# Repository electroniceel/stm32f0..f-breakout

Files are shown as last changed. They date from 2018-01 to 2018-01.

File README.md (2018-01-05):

STM32F0..F (TSSOP20) Breakout Module
====================================

A breakout module for STM32F0 microcontrollers in TSSOP20 footprint.

Basic Features
--------------

* Focus on small footprint and direct access to all pins.
* Provides a 8 pin Micro-MaTch header for easy access to SWD and UART.
* Pushbutton for Reset (press <1 second) and starting the bootloader (press >3 seconds).
* Onboard LDO regulator (standard SOT-23-5) can be used for VDD and VDDA, just VDD or disabled completely.
* Use of a crystal (SMT 3.2x2.5mm) is optional.
* Options can be configured using solder bridges.
* Power LED and User LED (on PA0, PF1 or disconnected).
* Size: 20x32mm or 10x8 pins in the standard 2.54mm raster

Currently supported microcontrollers
------------------------------------

* STM32F030F4
* STM32F031F4
* STM32F031F6
* STM32F038F6
* STM32F042F4 (USB header must be connected externally)
* STM32F042F6 (USB header must be connected externally)
* STM32F070F6 (USB header must be connected externally)

Schematics & Layout
-------------------

Schematics & Layout were done in KiCAD.

[Schematics as PDF](https://github.com/electroniceel/stm32f0..f-breakout/raw/master/schematics.pdf)

Picture
-------

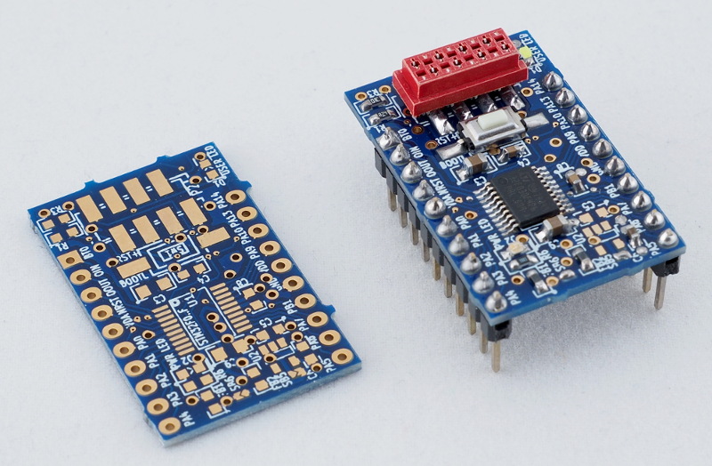
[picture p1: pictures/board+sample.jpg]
Module and raw PCB


License
-------


This work is licensed under a [Creative Commons Attribution 4.0 International License](https://creativecommons.org/licenses/by/4.0/).

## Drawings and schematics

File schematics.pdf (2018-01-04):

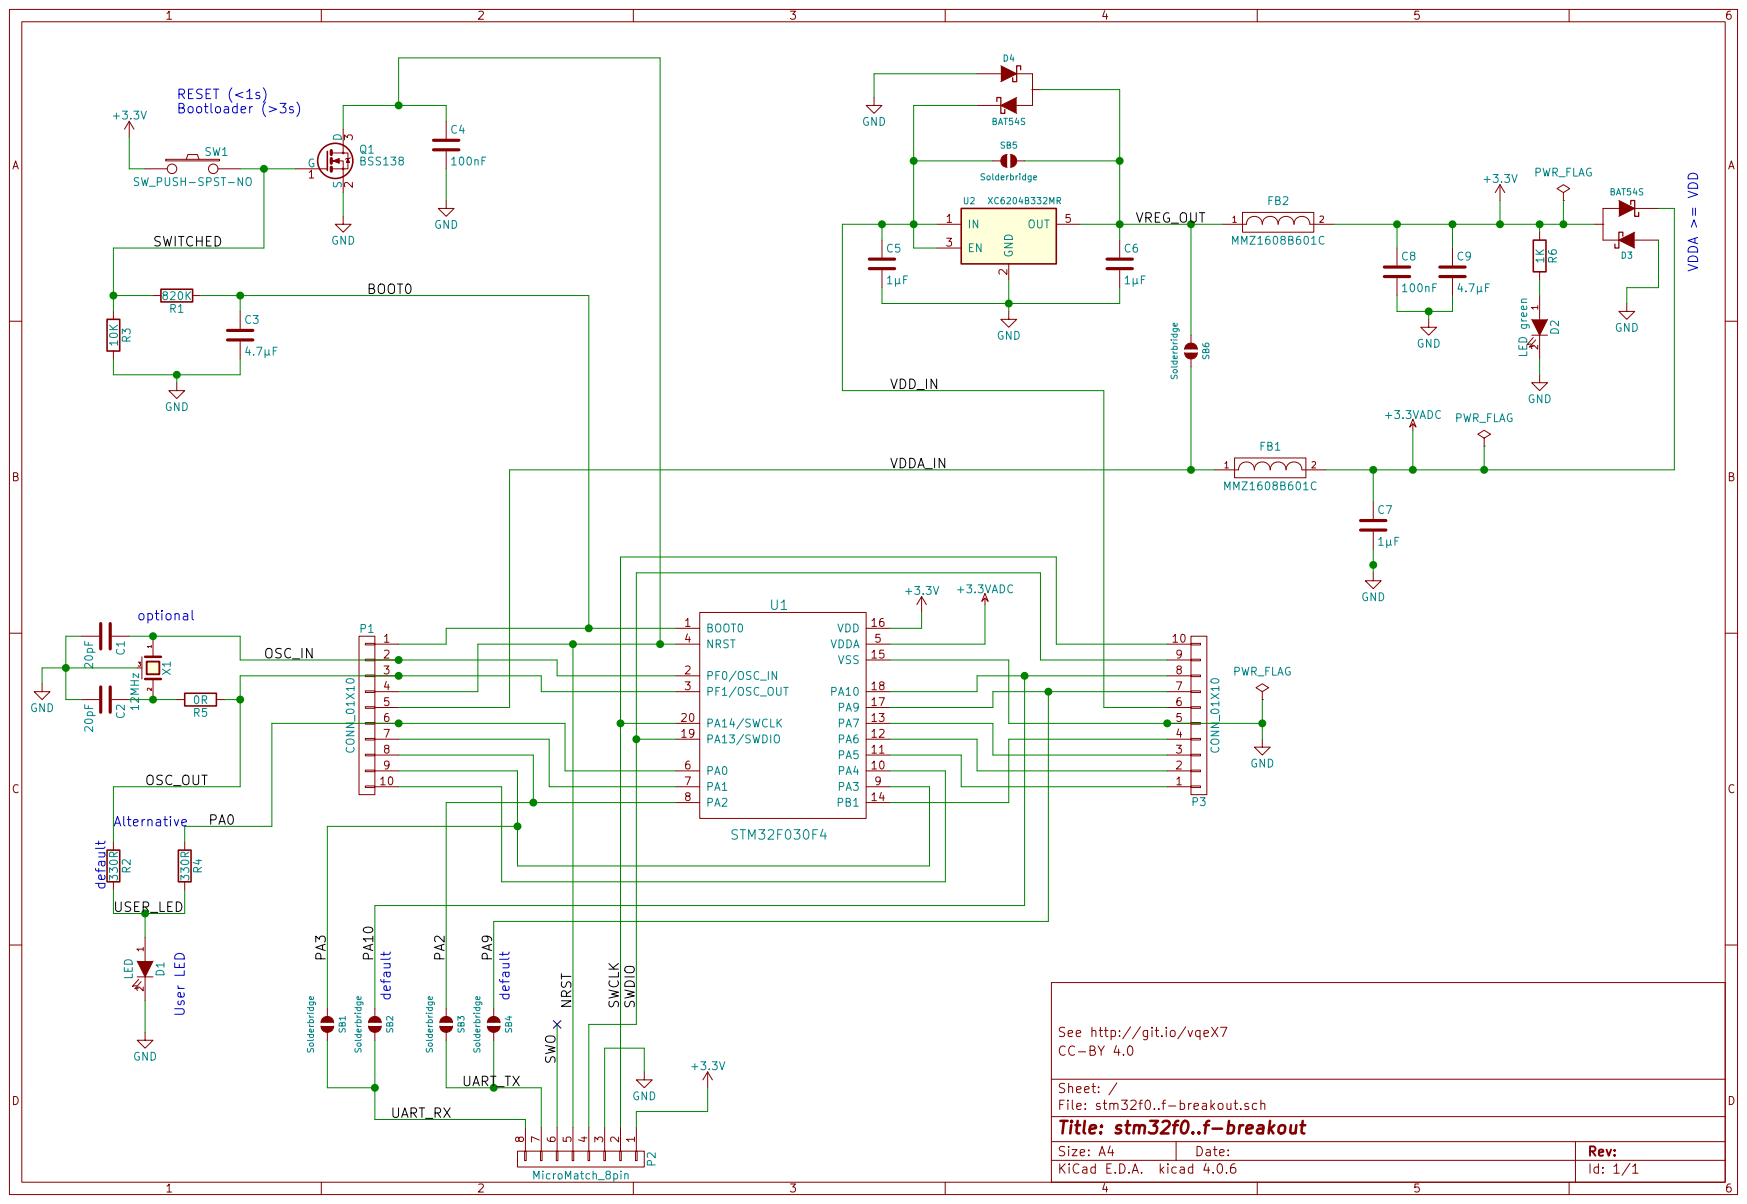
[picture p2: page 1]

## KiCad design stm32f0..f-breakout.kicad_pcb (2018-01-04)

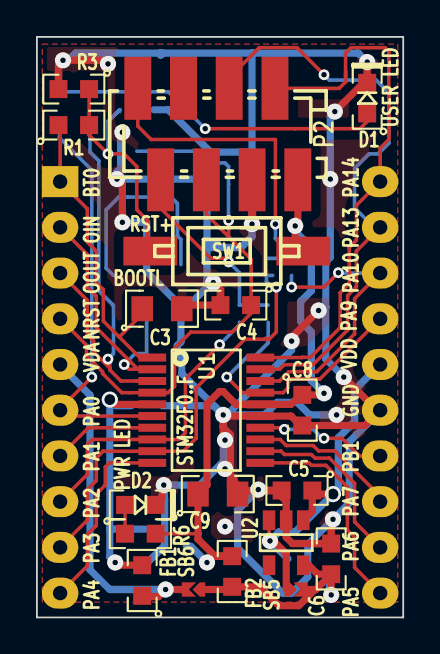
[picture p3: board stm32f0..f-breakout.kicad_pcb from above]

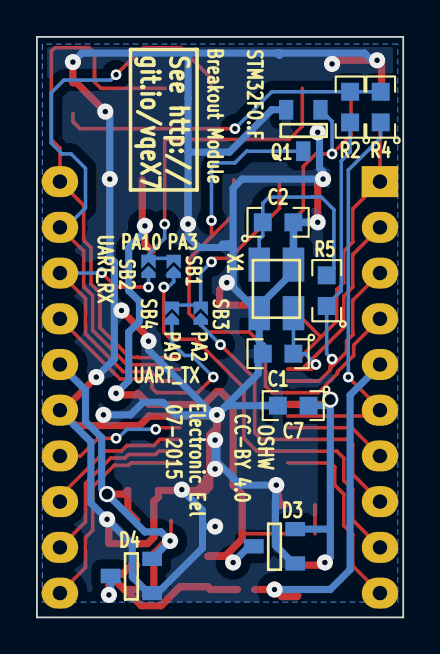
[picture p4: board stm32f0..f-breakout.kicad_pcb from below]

Board: 2 copper layers, 20.4 x 32.2 mm, 35 parts (16 on the bottom side), 29 nets.

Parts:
C1, C2: 20pF; SMD0603-wide-C
C3, C9: 4.7µF; SMD0805-wide-C
C4, C8: 100nF; SMD0603-wide-C
C5, C6, C7: 1µF; SMD0603-wide-C
D1: LED; SMD0603-wide-diode
D2: LED green; SMD0603-wide-diode
D3, D4: BAT54S; SOT-23
FB1, FB2: MMZ1608B601C; SMD0603-wide
P1, P3: CONN_01X10; Pin_Header_Straight_1x10
P2: MicroMatch_8pin; Conn-Micromatch-SMD-8
Q1: BSS138; SOT-23
R1: 820K; SMD0603-wide-R
R2, R4: 330R; SMD0603-wide-R
R3: 10K; SMD0603-wide-R
R5: 0R; SMD0603-wide-R
R6: 1K; SMD0603-wide-R
SB1, SB2, SB3, SB4, SB5, SB6: Solderbridge
SW1: SW_PUSH-SPST-NO; Push-Button-SMD-6.0x3.5mm
U1: STM32F030F4; TSSOP-20_4.4x6.5mm_Pitch0.65mm
U2: XC6204B332MR; SOT-23-5
X1: 12MHz; smd-xtal-3225

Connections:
+3.3VADC: C7.1, D3.2, FB1.2, U1.5
+3V3: C8.1, C9.1, D3.3, FB2.2, P2.1, R6.1, SW1.1, U1.16
/BOOT0: C3.1, P1.1, R1.1, U1.1
/NRST: C4.1, P1.4, P2.5, Q1.3, U1.4
/OSC_IN: C1.1, P1.2, U1.2, X1.1
/OSC_OUT: P1.3, R2.1, R5.1, U1.3
/PA0: P1.6, R4.1, U1.6
/PA2: P1.8, SB3.1, U1.8
/PA3: P1.9, SB1.1, U1.9
/PA9: P3.7, SB4.1, U1.17
/PA10: P3.8, SB2.1, U1.18
/SWCLK: P2.2, P3.10, U1.20
/SWDIO: P2.4, P3.9, U1.19
/SWITCHED: Q1.1, R1.2, R3.1, SW1.2
/UART_RX: P2.8, SB1.2, SB2.2
/UART_TX: P2.7, SB3.2, SB4.2
/USER_LED: D1.1, R2.2, R4.2
/VDDA_IN: FB1.1, P1.5, SB6.2
/VDD_IN: C5.1, D4.2, P3.6, SB5.1, U2.1, U2.3
/VREG_OUT: C6.1, D4.3, FB2.1, SB5.2, SB6.1, U2.5
GND: C1.2, C2.2, C3.2, C4.2, C5.2, C6.2, C7.2, C8.2, C9.2, D1.2, D2.2, D3.1, D4.1, P2.3, P3.5, Q1.2, R3.2, U1.15, U2.2, X1.3
unnamed: C2.1, R5.2, X1.2
unnamed: D2.1, R6.2
unnamed: P1.7, U1.7
unnamed: P1.10, U1.10
unnamed: P3.1, U1.11
unnamed: P3.2, U1.12
unnamed: P3.3, U1.13
unnamed: P3.4, U1.14

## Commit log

2018-01-04 add actual kicad design files
    [stm32f0..f-breakout.kicad_pcb, stm32f0..f-breakout.sch]
2018-01-04 add pictures and schematics.pdf

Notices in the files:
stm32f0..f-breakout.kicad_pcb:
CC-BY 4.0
